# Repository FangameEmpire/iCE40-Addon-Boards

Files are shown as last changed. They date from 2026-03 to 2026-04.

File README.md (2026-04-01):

# iCE40-Addon-Boards
A collection of add-on boards containing an iCE40 FPGA and the required supporting logic. Used to add FPGA functionality to existing hardware platforms, particularly microcontrollers. The boards are currently a work in progress. Currently, development prototypes are being tested, and the add-on boards will be designed once testing is complete.

## Planned platforms for add-on boards
-Arduino Uno

-Raspberry Pi Pico

-Seeed XIAO

-Adafruit Feather?

-QWIIC-only breakout?

## Testing hardware
iCE40 Breakout

## Addon board mockups
Work-in-progress screenshots of boards still being designed.
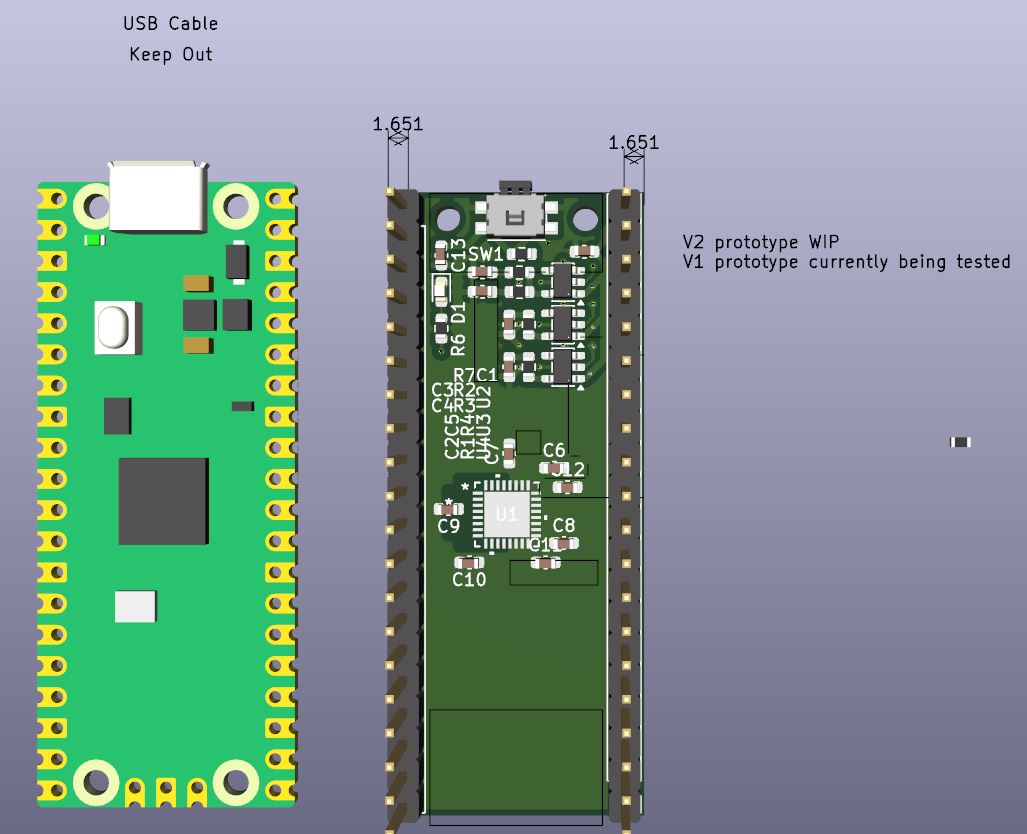
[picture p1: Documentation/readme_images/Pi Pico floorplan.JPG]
Pi Pico floorplan

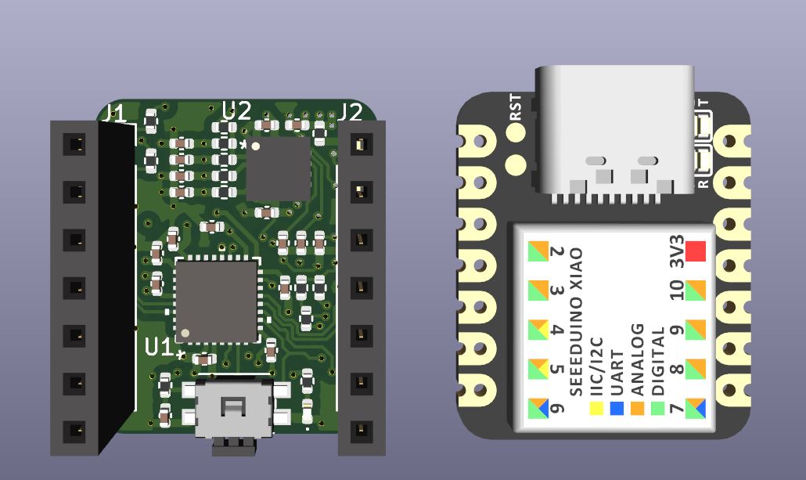
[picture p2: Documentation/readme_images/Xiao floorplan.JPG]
Xiao floorplan


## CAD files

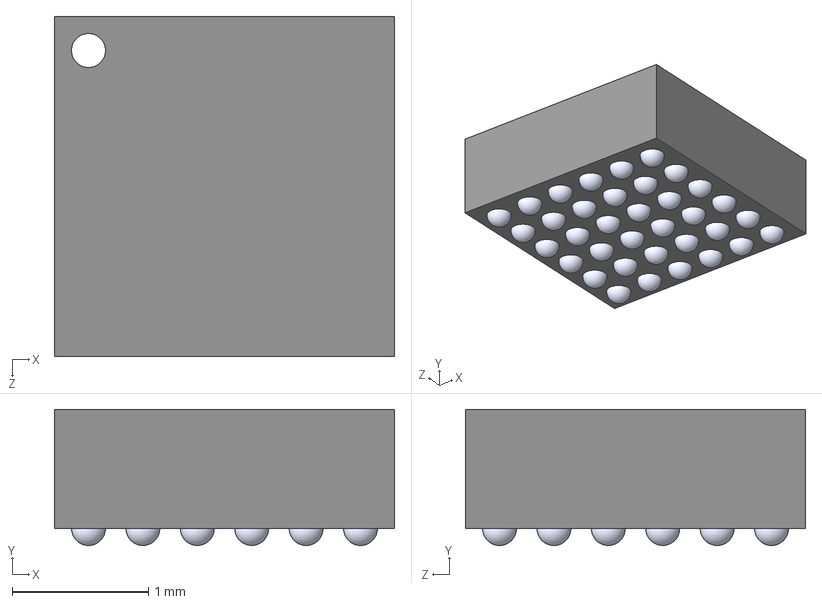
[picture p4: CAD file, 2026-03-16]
PiPico_iCE40UL1K_Addon/ICE40UL1K_CM36AI/ICE40UL1K-CM36AI--3DModel-STEP-269445.STEP
2.50 x 1.00 x 2.50 mm

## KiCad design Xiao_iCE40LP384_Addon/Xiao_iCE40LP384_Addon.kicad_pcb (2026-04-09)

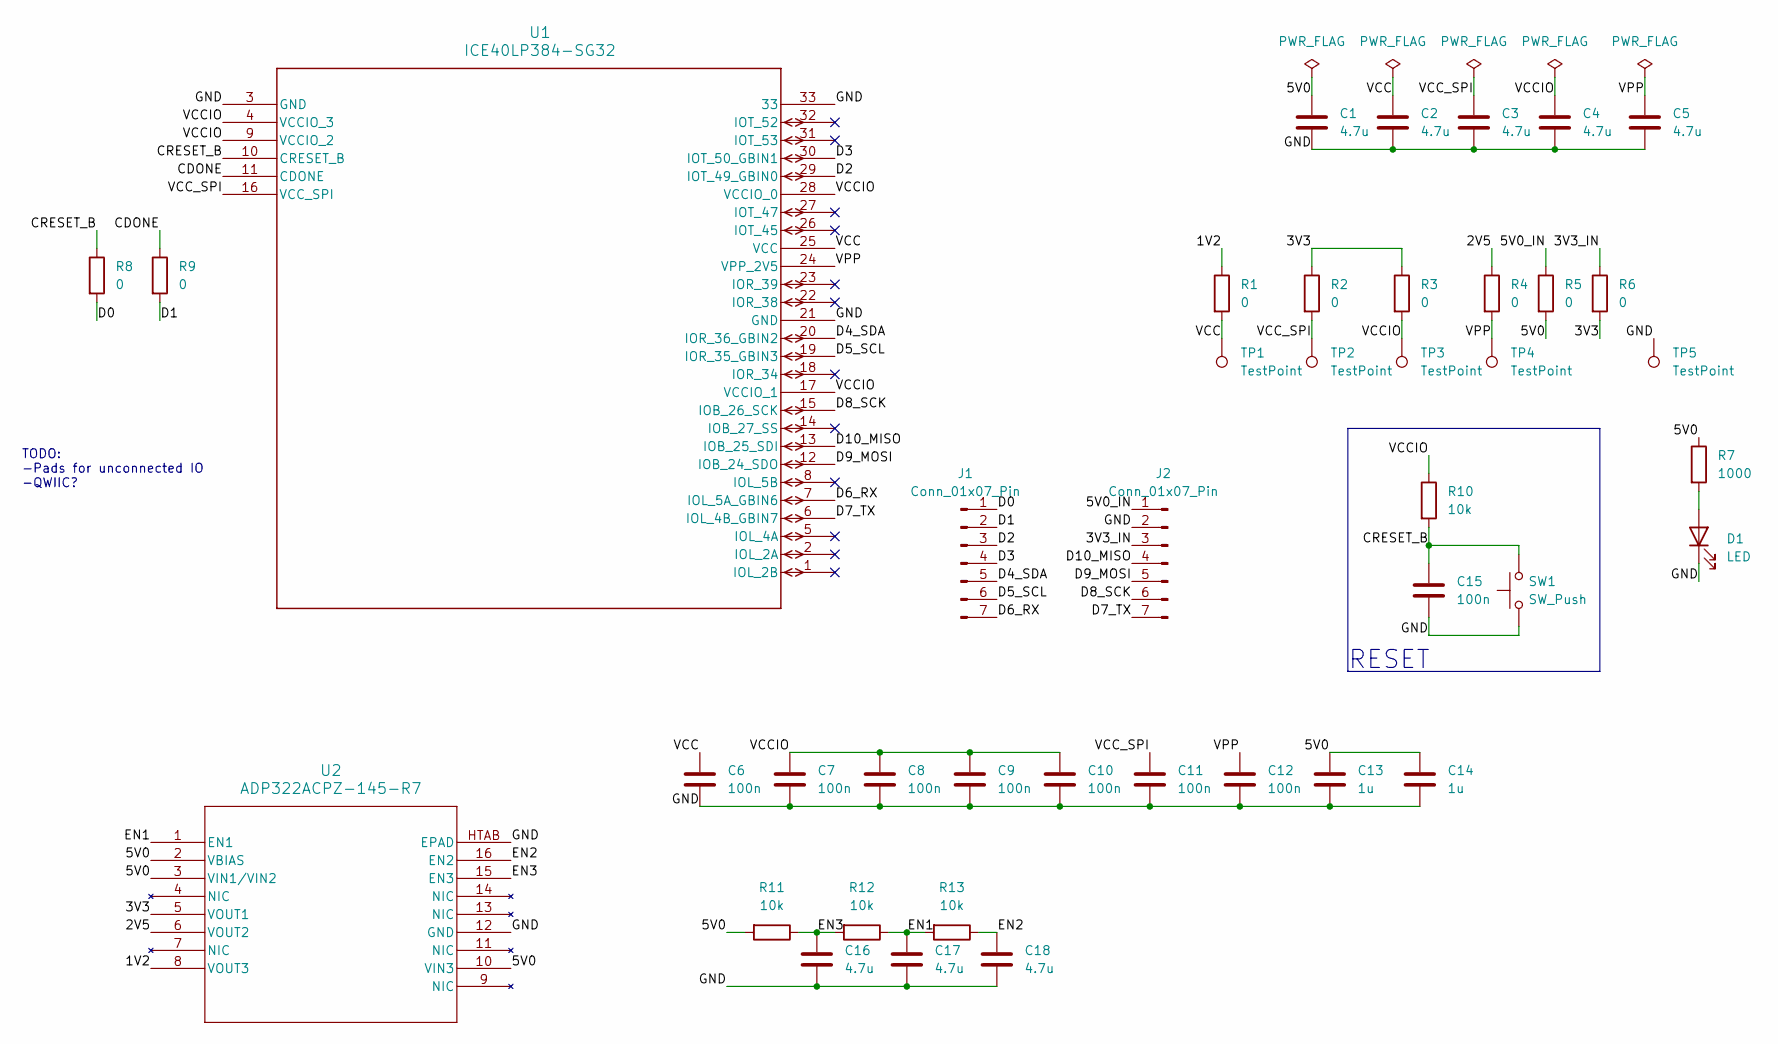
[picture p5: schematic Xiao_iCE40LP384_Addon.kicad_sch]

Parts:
C1, C2, C3, C4, C5, C16, C17, C18: 4.7u; C_0402_1005Metric
C6, C7, C8, C9, C10, C11, C12, C15: 100n; C_0402_1005Metric
C13, C14: 1u; C_0402_1005Metric
D1: LED; LED_0603_1608Metric
J1, J2: Conn_01x07_Pin; PinSocket_1x07_P2.54mm_Vertical
R1, R2, R3, R4, R5, R6, R8, R9: 0; R_0402_1005Metric
R7: 1000; R_0402_1005Metric
R10, R11, R12, R13: 10k; R_0402_1005Metric
SW1: SW_Push; Panasonic_EVQPUJ_EVQPUA
TP1, TP2, TP3, TP4, TP5: TestPoint; TestPoint_Pad_1.0x1.0mm
U1: ICE40LP384-SG32; QFNS32_LAT
U2: ADP322ACPZ-145-R7; CP_16_22_ADI

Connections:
/1V2: R1.1, U2.8 (VOUT3)
/2V5: R4.1, U2.6 (VOUT2)
/3V3: R2.1, R3.1, R6.2, U2.5 (VOUT1)
/3V3_IN: J2.3, R6.1
/5V0: C1.1, C13.1, C14.1, R5.2, R7.1, R11.2, U2.2 (VBIAS), U2.3 (VIN1/VIN2), U2.10 (VIN3)
/5V0_IN: J2.1, R5.1
/CDONE: R9.1, U1.11 (CDONE)
/CRESET_B: C15.1, R8.1, R10.2, SW1.2, U1.10 (CRESET_B)
/D0: J1.1, R8.2
/D1: J1.2, R9.2
/D2: J1.3, U1.29 (IOT_49_GBIN0)
/D3: J1.4, U1.30 (IOT_50_GBIN1)
/D4_SDA: J1.5, U1.20 (IOR_36_GBIN2)
/D5_SCL: J1.6, U1.19 (IOR_35_GBIN3)
/D6_RX: J1.7, U1.7 (IOL_5A_GBIN6)
/D7_TX: J2.7, U1.6 (IOL_4B_GBIN7)
/D8_SCK: J2.6, U1.15 (IOB_26_SCK)
/D9_MOSI: J2.5, U1.12 (IOB_24_SDO)
/D10_MISO: J2.4, U1.13 (IOB_25_SDI)
/EN1: C17.1, R12.1, R13.2, U2.1 (EN1)
/EN2: C18.1, R13.1, U2.16 (EN2)
/EN3: C16.1, R11.1, R12.2, U2.15 (EN3)
/GND: C1.2, C2.2, C3.2, C4.2, C5.2, C6.2, C7.2, C8.2, C9.2, C10.2, C11.2, C12.2, C13.2, C14.2, C15.2, C16.2, C17.2, C18.2, D1.1 (K), J2.2, SW1.1, TP5.1, U1.3 (GND), U1.21 (GND), U1.33, U2.12 (GND), U2.HTAB (EPAD)
/VCC: C2.1, C6.1, R1.2, TP1.1, U1.25 (VCC)
/VCCIO: C4.1, C7.1, C8.1, C9.1, C10.1, R3.2, R10.1, TP3.1, U1.4 (VCCIO_3), U1.9 (VCCIO_2), U1.17 (VCCIO_1), U1.28 (VCCIO_0)
/VCC_SPI: C3.1, C11.1, R2.2, TP2.1, U1.16 (VCC_SPI)
/VPP: C5.1, C12.1, R4.2, TP4.1, U1.24 (VPP_2V5)
unnamed: D1.2 (A), R7.2

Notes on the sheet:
RESET
TODO: -Pads for unconnected IO -QWIIC?

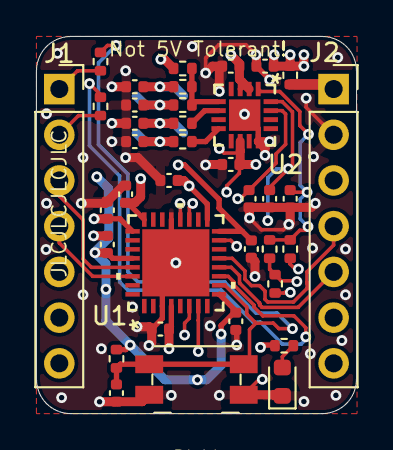
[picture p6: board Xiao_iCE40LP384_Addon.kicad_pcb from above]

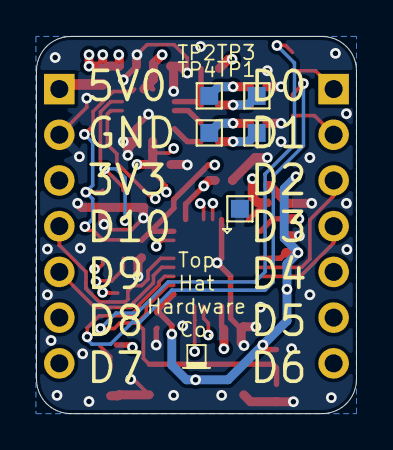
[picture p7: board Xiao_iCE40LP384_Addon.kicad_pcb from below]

Board: 4 copper layers, 17.8 x 21.0 mm, 42 parts (5 on the bottom side), 28 nets.

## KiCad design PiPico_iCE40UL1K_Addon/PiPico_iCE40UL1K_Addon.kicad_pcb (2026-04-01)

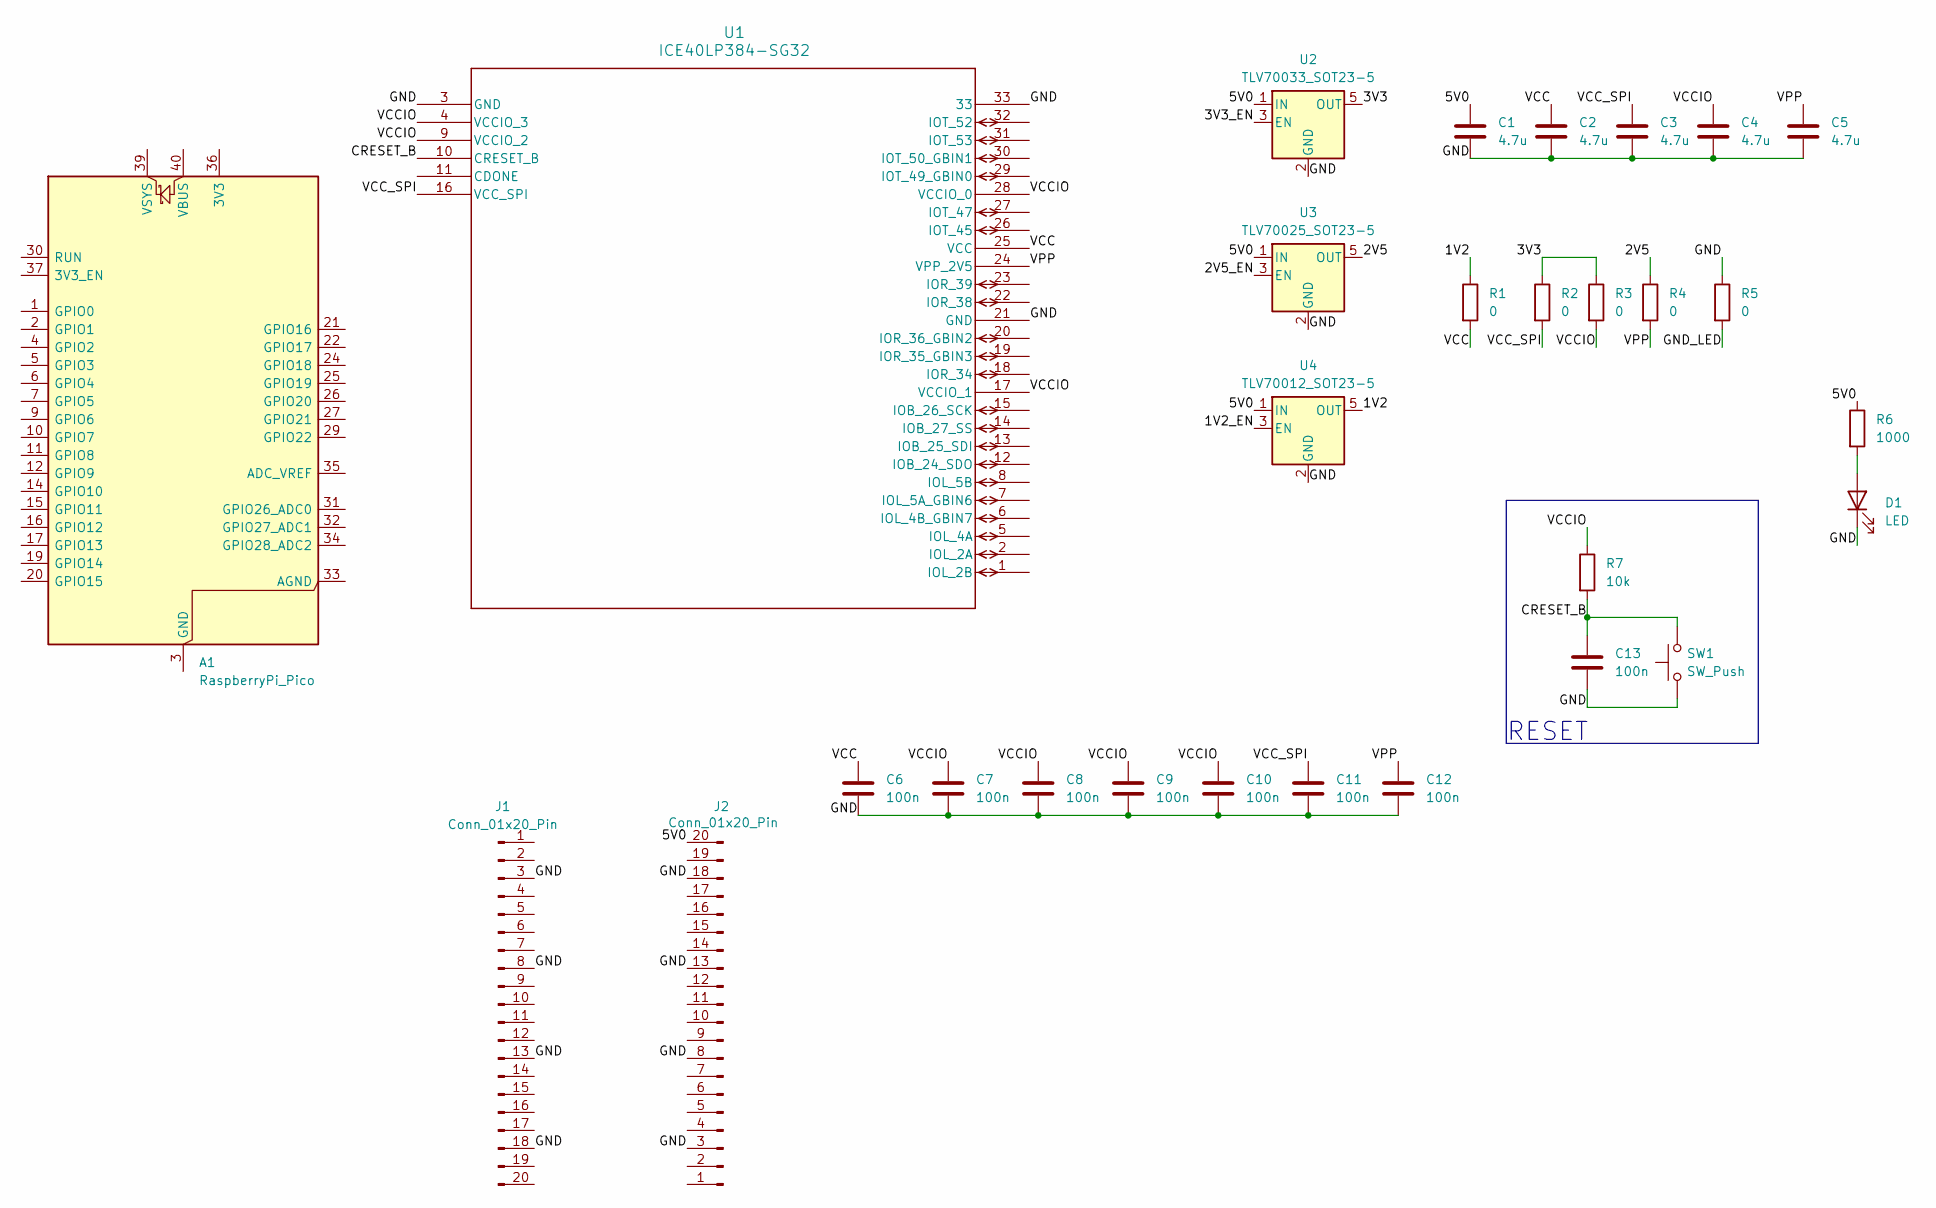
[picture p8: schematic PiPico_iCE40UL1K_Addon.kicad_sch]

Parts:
A1: RaspberryPi_Pico; RaspberryPi_Pico_Common_Unspecified
C1, C2, C3, C4, C5: 4.7u; C_0603_1608Metric
C6, C7, C8, C9, C10, C11, C12, C13: 100n; C_0603_1608Metric
D1: LED; LED_0603_1608Metric
J1, J2: Conn_01x20_Pin; PinHeader_1x20_P2.54mm_Vertical
R1, R2, R3, R4, R5: 0; R_0603_1608Metric
R6: 1000; R_0603_1608Metric
R7: 10k; R_0603_1608Metric
SW1: SW_Push; Panasonic_EVQPUJ_EVQPUA
U1: ICE40LP384-SG32; QFNS32_LAT
U2: TLV70033_SOT23-5; SOT-23-5
U3: TLV70025_SOT23-5; SOT-23-5
U4: TLV70012_SOT23-5; SOT-23-5

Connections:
/1V2: R1.1, U4.5 (OUT)
/1V2_EN: U4.3 (EN)
/2V5: R4.1, U3.5 (OUT)
/2V5_EN: U3.3 (EN)
/3V3: R2.1, R3.1, U2.5 (OUT)
/3V3_EN: U2.3 (EN)
/5V0: C1.1, J2.20, R6.1, U2.1 (IN), U3.1 (IN), U4.1 (IN)
/CRESET_B: C13.1, R7.2, SW1.2, U1.10 (CRESET_B)
/GND: C1.2, C2.2, C3.2, C4.2, C5.2, C6.2, C7.2, C8.2, C9.2, C10.2, C11.2, C12.2, C13.2, D1.1 (K), J1.3, J1.8, J1.13, J1.18, J2.3, J2.8, J2.13, J2.18, R5.1, SW1.1, U1.3 (GND), U1.21 (GND), U1.33, U2.2 (GND), U3.2 (GND), U4.2 (GND)
/GND_LED: R5.2
/VCC: C2.1, C6.1, R1.2, U1.25 (VCC)
/VCCIO: C4.1, C7.1, C8.1, C9.1, C10.1, R3.2, R7.1, U1.4 (VCCIO_3), U1.9 (VCCIO_2), U1.17 (VCCIO_1), U1.28 (VCCIO_0)
/VCC_SPI: C3.1, C11.1, R2.2, U1.16 (VCC_SPI)
/VPP: C5.1, C12.1, R4.2, U1.24 (VPP_2V5)
unnamed: A1.3 (GND), A1.8 (GND), A1.13 (GND), A1.18 (GND), A1.23 (GND), A1.28 (GND), A1.38 (GND)
unnamed: D1.2 (A), R6.2

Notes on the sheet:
RESET

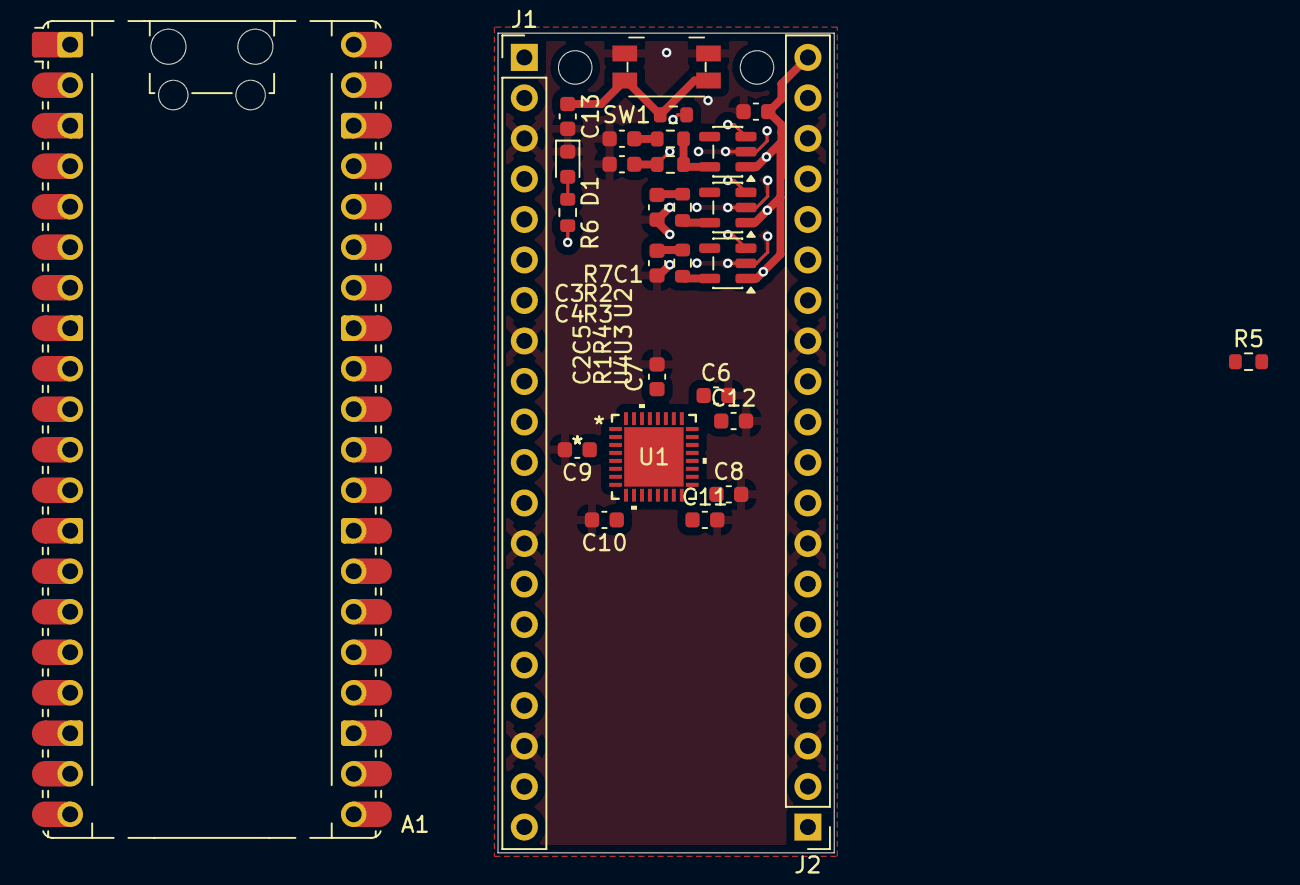
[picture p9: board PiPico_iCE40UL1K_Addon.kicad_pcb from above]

Board: 4 copper layers, 21.1 x 51.4 mm, 29 parts (0 on the bottom side), 12 nets.

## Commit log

2026-03-16 Started Pi Pico floorplanning
    [ICE40UL1K-CM36AI--3DModel-STEP-269445.STEP, PiPico_iCE40UL1K_Addon.kicad_pcb, PiPico_iCE40UL1K_Addon.kicad_sch]
2026-03-16 Add planned boards to readme
2026-03-23 Finished power supply placement and some routing. FPGA power from power supply not routed.
    [PiPico_iCE40UL1K_Addon.kicad_pcb]
2026-03-23 Update Pi Pico floorplan image with power supply layout
2026-03-31 Started XIAO breakout, did some basic floorplanning
    [PiPico_iCE40UL1K_Addon.kicad_sch, Xiao_iCE40LP384_Addon.kicad_pcb, Xiao_iCE40LP384_Addon.kicad_sch]
2026-04-01 Finished most of the XIAO floorplan, need to route FPGA caps
    [PiPico_iCE40UL1K_Addon.kicad_pcb, Xiao_iCE40LP384_Addon.kicad_pcb, Xiao_iCE40LP384_Addon.kicad_sch]
2026-04-03 XIAO done, as long as no problems come up during prototype testing
    [Xiao_iCE40LP384_Addon.kicad_pcb, Xiao_iCE40LP384_Addon.kicad_sch]
2026-04-03 Noted lack of 5V tolerance
    [Xiao_iCE40LP384_Addon.kicad_pcb]
2026-04-08 Improve silkscreen, fix ADP322 footprint error
    [Xiao_iCE40LP384_Addon-B_Cu.gbr, Xiao_iCE40LP384_Addon-B_Mask.gbr, Xiao_iCE40LP384_Addon-B_Paste.gbr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]
2026-04-09 Slow down RC timer and add test points to power supply
    [Xiao_iCE40LP384_Addon-B_Cu.gbr, Xiao_iCE40LP384_Addon-B_Mask.gbr, Xiao_iCE40LP384_Addon-B_Paste.gbr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]
2026-04-09 Slight improvements to ground
    [Xiao_iCE40LP384_Addon-B_Cu.gbr, Xiao_iCE40LP384_Addon-B_Mask.gbr, Xiao_iCE40LP384_Addon-B_Paste.gbr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]
2026-04-09 Gerbers.zip for manufacturing
